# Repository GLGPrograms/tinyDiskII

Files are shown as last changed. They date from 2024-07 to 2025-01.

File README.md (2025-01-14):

# tinyDiskII

Homemade floppy disk emulator for Apple II series computers

> :warning: **Work in progress**: read carefully the README before trying to reproduce this project!

tinyDiskII

tinyDiskII is able to simulate an [Apple Disk II](https://it.wikipedia.org/wiki/Disk_II) both in reading and writing.
Disk images are stored into a FAT16 formatted SD Card.
Each disk image must be a DOS 3.3 floppy image, saved as .NIC.
A cross platform .NIC <-> .DSK conversion tool will be available soon on this repository.
Floppy formatting is currently not supported, but it is currently under developement.

## BOM

| Reference(s) | Description | Notes |
| :--- | :---: | :---: |
| C1, C2, C3, C4, C5, C6, C8, C9, C10, C11, C12 | 0805 100n Capacitor | |
| D1, D2 | 0805 Red LED | |
| J1 | 2x3 male jumper | ICSP connector |
| J2 | SMD SD Card slot | |
| J3 | THT USB B Mini connector  |  Mount for USB debug |
| J4 | 2x10 male connector | DiskII connector |
| R5, R6 | 330 | |
| R2, R3, R4, R7, R8, R9, R10, R11, R12, R15 | 10k | |
| R13, R14 | 0 | Replaced with a bridge |
| SW1 | RotaryEncoder with switch | |
| U2 | SN74LVC244 | 5V tolerant buffer |
| U3 | CH340C |  Mount for USB debug |
| U4 | ATxmega16A4U-A | MCU |
| U5 | 74AHCT125 | Level shifter |
| U7 | 0.96" OLED I2C | 7-pin model |
| U10 | AP1117-33 |  3v3 linear regulator  |

### Do Not Place, reserved for future implementations

| Reference(s) | Feature |
| :--- | :---: |
| U1 | Flash/EEPROM interface |
| C12 | " |
| R1 | " |
| C13, C14 | USB ESD |
| R13, R14 | " |
| D3, D4 | " |
| C7 | USB self reset |
| J5 |  Debugging connector |

## Schematics and PCB

> :warning: Schematics and PCB layout can be found in `/schematics` folder. Please note that I had physically implemented only rev1.0, which requires some hardware patches. The issues were fixed in rev1.1, but I never put it into production. Build it at your own risk.

## Firmware

Firmware source code is in `/firmware` folder.
Code can be compiled on a linux/wsl machine through `make` command.
Make sure you have `make` and `avr-gcc` toolchanin installed.
Output binary will be generated as `/firmware/output/tinyDiskII.hex`.

In `/firmware/tests` there are some unit tests that can run on host system.
They can be compiled and executed with:

```bash
cd firmware/tests
cmake -B build .
cd build
cmake --build .
./tinyDiskII-tests
```

### Command line linterface

The serial interface is mainly used for application logging.
If no OLED display is detected, the serial interface is enabled for receiving commands.
If the OLED is connected, the command interpreter is disabled to avoid conflicts.

The following table resumes the available commands.

| Command | Arguments  | Description |
| :--- | :--- | :--- |
| `INIT`  | none | Initialize the SD Card (1) |
| `CWD` | `dirname`  | Change woring directory to `dirname` |
| `UP` | none | Change working director to the parent directory |
| `LST` | none | List files and directory in the current working directory |
| `SET` | `filename` | Select `filename`, in current working directory, as currently inserted disk (2) |
| `REM` | none | Remove currently inserted disk |
| `FAT` | `upto` | Prints FAT entries of selected file up to index `upto` (debug) |
| `INFO`  | `t` `s` | Prints .NIC file informations about sector `s` in track `t` (debug) |

1. If OLED is not connected, the SD Card must be manually initialized.
2. At startup, no disk is inserted.

## Changelog

* rev1.0: first version
* rev1.1: fixes the issues present in rev1.0:

  * LV_DISK_READ connected to U4 pin 21;
  * SD_WP connected to U4 pin 22;
  * SD_DETECT connected to U4 pin 23;
  * Added 10K pull-up resistor to DISK_WRITE_EN;
  * Pin 4 and 16 of U3 are shorted together.

## Contributors and references

* The whole projects borns as a custom implementation of Koichi Nishida's SdiskII [[1]](https://tulip-house.ddo.jp/digital/SDISK2/english.html) [[2]](https://github.com/suaide/SDisk2), which I used as a starting point for firmware developement.
* Jörg Hagedorn made a replica of the tinyDiskII hardware rev1.1 and he found a bug in the SD sector's addressing, now fixed.
* Kamen Angelov made a replica of the tinyDiskII hardware rev1.1, he found a bug with SDHC card and he sent some fix proposal.

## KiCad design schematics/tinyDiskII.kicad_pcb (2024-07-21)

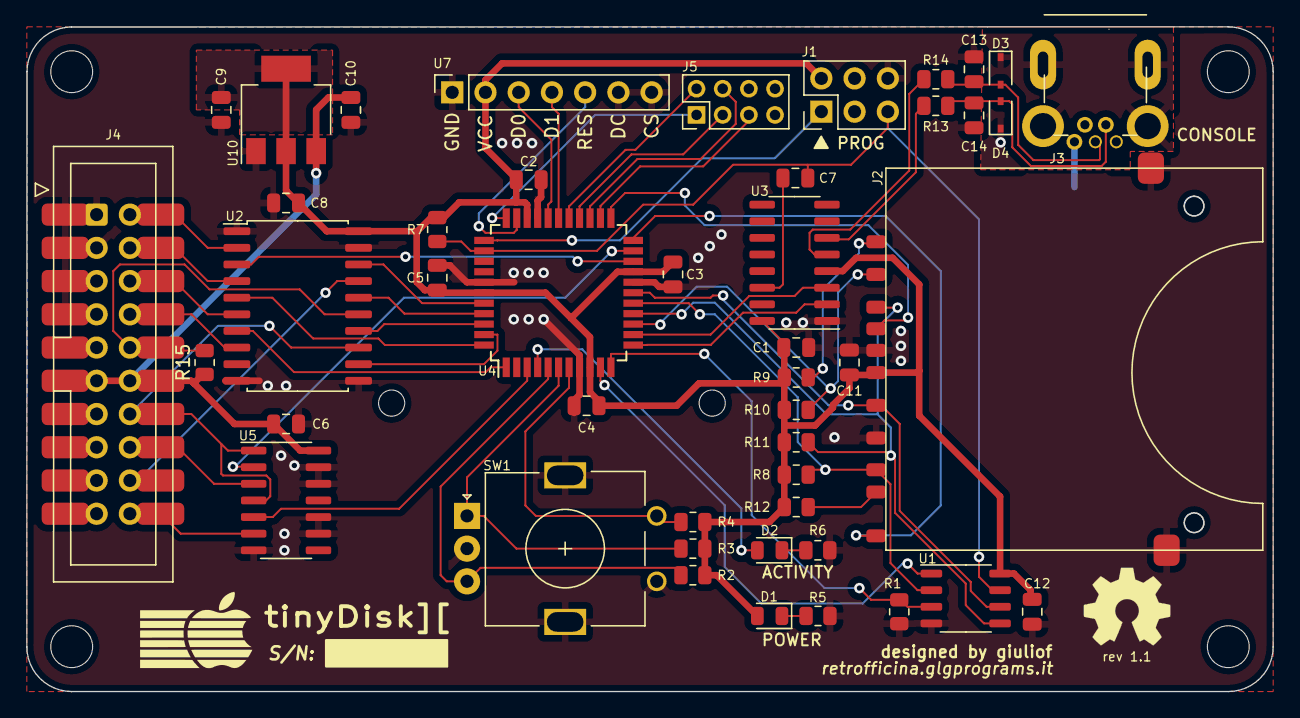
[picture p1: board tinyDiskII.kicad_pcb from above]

Board: 2 copper layers, 95.3 x 50.8 mm, 52 parts (0 on the bottom side), 55 nets.

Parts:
C1, C3, C4, C5, C6, C8, C9, C10, C11, C12: 100n; C_0805_2012Metric
C7, C13, C14: C; C_0805_2012Metric
C?: 100n; C_0805_2012Metric
D1, D2: LED; LED_0805_2012Metric
D3, D4: -; D_SOD-323
H1, H2, H3, H4: MountingHole; MountingHole_3.2mm_M3
J2: SD_Card; SDCard
J3: USB_B_Mini; USB_Mini-B_THT_generic
J4: APPLEII_DISK_CONNECTOR; IDC-Header_2x10_P2.54mm
J5: Ext; PinHeader_2x04_P2.00mm_Vertical
J?: AVR-PDI-6; PinHeader_2x03_P2.54mm_Vertical
R1: R; R_0805_2012Metric
R2, R3, R4, R7, R8, R9, R10, R11, R12, R15: 10k; R_0805_2012Metric
R5, R6: 330; R_0805_2012Metric
R13, R14: 10; R_0805_2012Metric
SW1: RotaryEncoder_Switch
SYM1: GraphicSymbol; Apple_Logo
SYM2: Logo_Open_Hardware_Small; OSHW-Symbol_6.7x6mm_SilkScreen
U1: MX25R3235FM1xx0; SOP-8_3.9x4.9mm_P1.27mm
U2: SN74LVC244; SOIC-20W_7.5x12.8mm_P1.27mm
U3: CH340C; SOIC-16_3.9x9.9mm_P1.27mm
U5: 74AHCT125; SOIC-14_3.9x8.7mm_P1.27mm
U7: OLED_MULTI
U10: AP1117-33; SOT-223-3_TabPin2
U?: ATxmega16A4U-A; TQFP-44_10x10mm_P0.8mm

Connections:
+3V3: C1.1, C3.1, C4.1, C5.1, C8.1, C9.1, C11.1, C12.1, C?.1, D1.2 (A), J2.4 (VDD), J?.2 (VCC), R2.2, R3.2, R4.2, R7.2, R8.1, R9.1, R10.1, R11.1, R12.1, U1.8 (VCC), U2.20 (VCC), U3.4 (V3), U3.16 (VCC), U7.2 (VCC), U10.2 (VO), U?.9 (VCC), U?.19 (VCC), U?.31 (VCC), U?.39 (AVCC)
+5V: C6.1, C10.1, J4.11 (+5V), J4.12 (+5V), R15.1, U5.14 (VCC), U10.3 (VI)
/ACT_LED: D2.2 (A), U?.4 (AREFB/PB0)
/D'N: R14.1, U3.6 (UD-)
/D'P: R13.1, U3.5 (UD+)
/DAT1: J2.8 (DAT1), R12.2
/DAT2: J2.9 (DAT2), R9.2
/DISK_EN: J4.14 (EN), U2.13 (2A2), U5.1, U5.4
/DISK_READ: J4.16 (READ), U5.3
/DISK_WRITE: J4.18 (WRITE), U2.17 (2A0)
/DISK_WRITE_EN: J4.10 (WR_EN), R15.2, U2.15 (2A1)
/DN: C14.1, D4.2 (A2), J3.2 (D-), R14.2
/DP: C13.1, D3.2 (A2), J3.3 (D+), R13.2
/ENC_A: R3.1, SW1.A, U?.6 (PB2)
/ENC_B: R2.1, SW1.B, U?.5 (PB1)
/ENC_BTN: R4.1, SW1.S1, U?.7 (PB3)
/FLASH_CS: U1.1 (~CS), U?.10 (PC0)
/FLASH_WP: R1.2, U1.3 (~WP/SIO2), U?.11 (PC1)
/LV_DISK_EN: U2.7 (2Y2), U?.1 (PA5)
/LV_DISK_READ: U5.2, U?.21 (PD1)
/LV_DISK_WRITE: U2.3 (2Y0), U?.20 (PD0)
/LV_DISK_WRITE_EN: U2.5 (2Y1), U?.44 (PA4)
/LV_PHI0: U2.18 (1Y0), U?.40 (AREFA/PA0)
/LV_PHI1: U2.16 (1Y1), U?.41 (PA1)
/LV_PHI2: U2.14 (1Y2), U?.42 (PA2)
/LV_PHI3: U2.12 (1Y3), U?.43 (PA3)
/LV_WRITE_PROTECT: U5.5, U?.3 (PA7)
/OLED_RES: U7.5 (RES), U?.32 (PE2)
/OLED_SCL: U7.3 (D0), U?.29 (PE1)
/OLED_SDA: U7.4 (D1), U?.28 (PE0)
/PD4: J5.5, U?.24 (PD4)
/PD5: J5.4, U?.25 (PD5)
/PD6: J5.3, U?.26 (PD6)
/PD7: J5.2, U?.27 (PD7)
/PDI_CLK: C7.1, J?.5 (CLOCK), R7.1, U1.7 (~RESET/SIO3), U?.35 (~RESET/PDI_CLK)
/PDI_DATA: J?.1 (DATA), U?.34 (PDI_DATA)
/PE3: J5.1, U?.33 (PE3)
/PH0: J4.2 (PH0), U2.2 (1A0)
/PH1: J4.4 (PH1), U2.4 (1A1)
/PH2: J4.6 (PH2), U2.6 (1A2)
/PH3: J4.8 (PH3), U2.8 (1A3)
/SD_CS: J2.1 (CD/DAT3), R10.2, U?.14 (PC4)
/SD_DETECT: J2.10 (CARD_DETECT), U?.23 (PD3)
/SD_WP: J2.11 (WRITE_PROTECT), U?.22 (PD2)
/SPI_MISO: J2.7 (DAT0), R8.2, U1.2 (SO/SIO1), U?.16 (PC6)
/SPI_MOSI: J2.2 (CMD), R11.2, U1.5 (SI/SIO0), U?.15 (PC5)
/SPI_SCK: J2.5 (CLK), U1.6 (SCLK), U?.17 (PC7)
/UART_RXD: U3.2 (TXD), U?.12 (PC2)
/UART_TXD: U3.3 (RXD), U?.13 (PC3)
/USB_SHIELD: D3.1 (A1), D4.1 (A1), J3.6 (Shield)
/WRITE_PROTECT: J4.20 (PROTECT), U5.6
GND: C1.2, C3.2, C4.2, C5.2, C6.2, C8.2, C9.2, C10.2, C11.2, C12.2, C13.2, C14.2, C?.2, J2.3 (VSS), J2.6 (VSS), J2.12 (SHELL1), J2.13 (SHELL2), J3.5 (GND), J4.1 (GND), J4.3 (GND), J4.5 (GND), J4.7 (GND), J?.6 (GND), R1.1, R5.2, R6.2, SW1.C, SW1.MP (SHIELD), SW1.S2, U1.4 (GND), U2.1 (1OE), U2.10 (GND), U2.11 (2A3), U2.19 (2OE), U3.1 (GND), U5.7 (GND), U5.9, U5.10, U5.12, U5.13, U7.1 (GND), U7.6 (DC), U7.7 (CS), U10.1 (GND), U?.8 (GND), U?.18 (GND), U?.30 (GND), U?.38 (GND)
unnamed: C7.2, U3.14 (~RTS)
unnamed: D1.1 (K), R5.1
unnamed: D2.1 (K), R6.1

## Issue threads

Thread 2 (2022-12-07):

SD Card initialization fails after power up

giuliof, 2022-12-07:
Initialization completes correctly if a reset is issued.
Maybe an incorrect power up sequence?

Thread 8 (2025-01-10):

Addressing error with SDHC cards

giuliof, 2025-01-10:
Kamen Angelov made a replica of the project and found a bug when using SDHC  cards.
It that case command 17 (`SD_CMD_READ_SINGLE_BLOCK`) needs block unit address (512 bytes unit) instead of byte size unit.

This may be solved introducing the following patch code when giving the address to the `SD_CMD_READ_SINGLE_BLOCK` command.

```c
uint32_t addressToBlock(uint32_t address) {
    if (type == SD_SDHC) {
        return address / SDCARD_BLOCK_SIZE;
    }

    return address;
}
```

Further tests needed.

Closed 2025-01-14.

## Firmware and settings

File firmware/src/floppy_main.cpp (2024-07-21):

/* * * * * * * * * * * * * * * * *  INCLUDES  * * * * * * * * * * * * * * * * */

#include "floppy_main.h"

#include <avr/interrupt.h>
#include <avr/io.h>

#include <util/delay.h>

#include "sdcard.h"
#include "sdcard_nic.h"
#include "util/macro.h"
#include "util/port.h"

#include "debug.h"

/* * * * * * * * * * * * * PRIVATE MACROS AND DEFINES * * * * * * * * * * * * */

// Writing buffer size
#define WRITING_BUFFER_SIZE (350)
// Volume number is always the same
#define volume (0xFE)

// IO defines
#define FLOPPY_DISK_WRITE      D, 0
#define FLOPPY_PH              A, 0
#define FLOPPY_PH_MASK         0xF
#define FLOPPY_DISK_WRITE_EN   A, 4
#define FLOPPY_DISK_EN         A, 5
#define FLOPPY_DISK_READ_EX    A, 6
#define FLOPPY_DISK_READ       D, 1
#define FLOPPY_DISK_WRITE_PROT A, 7

#define WRITE_CAPABLE (true)

/* * * * * * * * * * * * * STATIC FUNCTION PROTOTYPES * * * * * * * * * * * * */

// Reading routines
static void abort_reading();
static void irq_reading();

// Writing routines
static uint8_t floppy_read_data();
static void init_writing();
static void end_writing();
static void check_data();
static void write_pinchange();
static void write_idle();
static void write_back(void);

/* * * * * * * * * * * * * * *  STATIC VARIABLES  * * * * * * * * * * * * * * */

// DISK II status
// Formatting operation has been detected
static bool formatting = false;
// Physical track
static uint8_t ph_track; // 0 - 69
// Disk sector
static uint8_t sector; // 0 - 15
// Number of read bits from NIC file sector (maximum of 512 bytes)
static uint16_t bitbyte; // 0 - (8*512-1)
static uint8_t write_buffer[WRITING_BUFFER_SIZE];
static uint8_t write_data = 0x00;
static uint8_t write_bitcount = 0;
static bool synced = false;
// Update sector request
static volatile bool prepare = true;

/* * * * * * * * * * * * * * *  STATIC FUNCTIONS  * * * * * * * * * * * * * * */

/* - - - - - - - - - - - - - - Low-level methods  - - - - - - - - - - - - - - */

static uint8_t floppy_write_in()
{
  return (Port(FLOPPY_DISK_WRITE).IN & PinMsk(FLOPPY_DISK_WRITE)) ? 1 : 0;
}

static uint8_t floppy_write_enable()
{
  return (Port(FLOPPY_DISK_WRITE_EN).IN & PinMsk(FLOPPY_DISK_WRITE_EN)) ? 0 : 1;
}

/* - - - - - - - - - - - - - floppy reading methods - - - - - - - - - - - - - */

static void abort_reading()
{
  if (bitbyte < (402 * 8))
  {
    nic_abort_read(bitbyte);
    bitbyte = 402 * 8;
  }
}

static void irq_reading()
{
  uint8_t readpulse;

  // disable match
  TCD0.CCB = 0xFFFF;

  // Still fetching data
  if (prepare)
    return;

  if (bitbyte < (402 * 8))
  {
    // Fetch bit from sdcard
    readpulse = nic_get_bit();

    // 3us low, then 1us high pulse
    if (readpulse)
      TCD0.CCB = 3e-6 * (F_CPU);

    bitbyte++;

    return;
  }

  prepare = true;
}

/* - - - - - - - - - - - - - floppy writing methods - - - - - - - - - - - - - */

static uint8_t floppy_read_data()
{
  static uint8_t magstate = 0;
  uint8_t old_magstate = magstate;
  magstate = floppy_write_in();
  return magstate ^ old_magstate;
}

// this function should be called when a write request is asserted
static void init_writing()
{
  cli();
  // Disable match
  TCD0.CCB = 0xFFFF;
  synced = false;
  write_bitcount = 0;
  floppy_read_data();
  TCD0.CNT = 0x0000;
  TCD0.INTFLAGS = TC0_OVFIF_bm;
}

// this function should be called when write request is de-asserted
static void end_writing()
{
  write_back();
  TCD0.CNT = 0x0000;
  TCD0.INTFLAGS = TC0_OVFIF_bm;
  sei();
}

static void check_data()
{
  static uint16_t bufsize;
  if (!synced && write_data == 0xD5)
  {
    synced = true;
    bufsize = 0;
    goto push;
  }

  if (synced && bufsize < WRITING_BUFFER_SIZE)
  {
    write_bitcount++;
    if (write_bitcount == 8)
    {
    push:
      write_bitcount = 0;
      write_buffer[bufsize++] = write_data;
    }
  }
}

static void write_pinchange()
{
  // disable match
  // TCD0.CCB = 0xFFFF;
  write_data <<= 1;
  write_data |= 1;
  TCD0.CNT = 0x0000;
  TCD0.INTFLAGS = TC0_OVFIF_bm;
  check_data();
}

static void write_idle()
{
  // disable match
  // TCD0.CCB = 0xFFFF;
  write_data <<= 1;
  TCD0.INTFLAGS = TC0_OVFIF_bm;
  check_data();
}

// write back writeData into the SD card
static void write_back(void)
{
  static unsigned char sec;

  // if (bit_is_set(PIND,3)) return;
  if (write_buffer[2] == 0xAD)
  {
    if (!formatting)
    {
      abort_reading();
      nic_write_sector(write_buffer, volume, ph_track >> 1, sector);
      write_buffer[2] = 0;
      prepare = true;
    }
    else
    {
      sector = sec;
      formatting = false;
      if (sec == 0xf)
      {
        // cancel reading
        abort_reading();
        prepare = true;
      }
    }
  }
  if (write_buffer[2] == 0x96)
  {
    sec = (((write_buffer[7] & 0x55) << 1) | (write_buffer[8] & 0x55));
    formatting = true;
  }
}

/* * * * * * * * * * * * * * *  GLOBAL FUNCTIONS  * * * * * * * * * * * * * * */

void floppy_init()
{
  // Input stepper
  Port(FLOPPY_PH).DIRCLR = FLOPPY_PH_MASK;

  bitbyte = 0;

  /*
   *
   *      /|     /|     /|     /|
   *     / |    / |    / |    / |
   *    /  |   /  |   /  |   /  |
   *   /   |  /   |  /   |  /   |
   *  /    | /    | /    | /    |
   * /     |/     |/     |/     |
   *      _      _             _
   * ____| |____| |___________| |
   *      1      1      0      1
   */

  // Timer. Set period to 4us,
  TCD0.PER = 4e-6 * (F_CPU);
  // PWM mode, output compare enabled on CCB
  TCD0.CTRLB = (TC_WGMODE_SINGLESLOPE_gc << TC0_WGMODE0_bp) | TC0_CCBEN_bm;
  // interrupt on overflow,
  TCD0.INTCTRLA = (TC_OVFINTLVL_HI_gc) << TC0_OVFIF_bp;

  // Inputs
  Port(FLOPPY_DISK_WRITE).DIRCLR = PinMsk(FLOPPY_DISK_WRITE);
  Port(FLOPPY_DISK_WRITE_EN).DIRCLR = PinMsk(FLOPPY_DISK_WRITE_EN);
  Port(FLOPPY_DISK_EN).DIRCLR = PinMsk(FLOPPY_DISK_EN);
  Port(FLOPPY_DISK_READ_EX).DIRCLR = PinMsk(FLOPPY_DISK_READ_EX);
  // Outputs
  Port(FLOPPY_DISK_READ).DIRSET = PinMsk(FLOPPY_DISK_READ);
  Port(FLOPPY_DISK_WRITE_PROT).DIRSET = PinMsk(FLOPPY_DISK_WRITE_PROT);

  // output compare enabled (inverted)
  Port(FLOPPY_DISK_READ).PIN1CTRL = PORT_INVEN_bm;
  // output compare register to MAX?
  TCD0.CCB = 0xFFFF;

  // Enable clock to the TCD0
  TCD0.CTRLA = TC_CLKSEL_DIV1_gc;
}

/* - - - - - - - - - - - - - - Low-level methods  - - - - - - - - - - - - - - */

void floppy_write_protect(bool protect)
{
  if (protect)
    Port(FLOPPY_DISK_WRITE_PROT).OUTSET = PinMsk(FLOPPY_DISK_WRITE_PROT);
  else
    Port(FLOPPY_DISK_WRITE_PROT).OUTCLR = PinMsk(FLOPPY_DISK_WRITE_PROT);
}

bool floppy_drive_enabled()
{
  if (Port(FLOPPY_DISK_EN).IN & PinMsk(FLOPPY_DISK_EN))
    return false;
  return true;
}

// Timer IRQ: called every 4us to output data signal (see comment in floppy_init)
ISR(TCD0_OVF_vect)
{
  irq_reading();
}

/* - - - - - - - - - - - - - - High-level methods - - - - - - - - - - - - - - */

void floppy_main()
{
  // Current stepper offset (0 to 3)
  static uint8_t ofs = 0;
  // Latest stepper offset
  static uint8_t old_ofs = 0;

  // Prepare variables
  cli();
  bitbyte = 0;
  prepare = true;
  // Leave track at last position...
  // ph_track = 0;
  sector = 0;
  sei();

  while (floppy_drive_enabled())
  {
    // Prepare for writing?
    if (WRITE_CAPABLE && floppy_write_enable())
    {
      init_writing();

      uint8_t magstate = floppy_write_in();

      do
      {
        uint8_t new_magstate = floppy_write_in();
        if (magstate != new_magstate)
        {
          write_pinchange();
          magstate = new_magstate;
        }
        if (TCD0.INTFLAGS & TC0_OVFIF_bm)
        {
          write_idle();
        }
      } while (floppy_write_enable());

      end_writing();
    }


    /* * * Update physical track position * * */
    uint8_t stp_pos = (Port(FLOPPY_PH).IN & FLOPPY_PH_MASK);

    ofs = ((stp_pos == 0b00001000)
               ? 3
               : ((stp_pos == 0b00000100)
                      ? 2
                      : ((stp_pos == 0b00000010) ? 1
                                                 : ((stp_pos == 0b00000001) ? 0 : ofs))));
    if (ofs != old_ofs)
    {
      if (ofs == ((old_ofs + 1) & 0x3))
        ph_track++;
      else if (ofs == ((old_ofs - 1) & 0x3))
        ph_track--;

      old_ofs = ofs;

      // < 0
      if (ph_track > 70)
        ph_track = 0;
      // > fine tracce
      else if (ph_track > 69)
        ph_track = 69;

      // DEBUG good old printf debug
      // debug_printP(PSTR("%x\n\r"), ph_track);
      // ... do not interrupt a sector reading when changing track
    }

    if (prepare)
    {
      // mute interrupts during update. 0 will be sent
      cli();

      if (bitbyte == (402 * 8))
      {
        // Sector is ended,
        // discard 112 byte (including CRC 2 byte)
        nic_abort_read(bitbyte);
      }

      sdcard_set_mode(SPI, 1);

      // Move to the next sector circularly
      // Sectors does not have a particular alignemnt between track and track.
      // Then, sector is always incremented
      sector = ((sector + 1) & 0xf);
      nic_update_sector(ph_track >> 1, sector);
      bitbyte = 0;
      prepare = false;

      sdcard_set_mode(BITBANG_FAST, 0);

      sei();
    }
  }

  debug_printP(PSTR("Reading done\n\r"));

  // wait till last irq
  while (!prepare)
    ;
  if (bitbyte == (402 * 8))
  {
    // Sector is ended,
    // discard 112 byte (including CRC 2 byte)
    nic_abort_read(bitbyte);
  }

  sdcard_set_mode(SPI, 1);

  bitbyte = 0;
  ph_track = 0;
  ofs = 0;
  old_ofs = 0;
}

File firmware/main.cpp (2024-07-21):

/**
 * @file main.c
 * @author Giulio (giulio@glgprograms.it)
 * @brief Kickstart and setup code
 * @version 0.1
 * @date 2022-03-03
 *
 * @copyright Copyright (c) 2022
 *
 */

#include <avr/interrupt.h>
#include <avr/io.h>
#include <util/delay.h>

#include "src/clock.h"
#include "src/floppy_main.h"
#include "src/prompt.h"
#include "util/port.h"

#include "src/sdcard.h"
#include "src/sdcard_gpio.h"
#include "src/sdcard_nic.h"
#include "src/sdcard_fat.h"

#include "src/oled_gui.h"
#include "src/oled_lcd.h"
#include "src/encoder.h"

#include "debug.h"

// Enable GUI
#define DISPLAY_ENABLED (true)

static void cli_mainloop() __attribute__((noreturn));
static void gui_mainloop() __attribute__((noreturn));
static void display_update_file_list(uint16_t fat_idx);

int main()
{
  // If display is not connected or disabled, use CLI
  bool cli_mode = true;

  // Set up PLL to reach desired clock speed
  clk_init();

  // Configure SDcard I/O
  sdcard_init();

  // Configure prompt uart
  prompt_init();

  // Configure floppy
  floppy_init();

  // Initialize OLED display
  if (DISPLAY_ENABLED)
    cli_mode = !oled_init();

  PMIC.CTRL |= PMIC_HILVLEN_bm | PMIC_MEDLVLEN_bm | PMIC_LOLVLEN_bm;
  sei();

  if (cli_mode)
    cli_mainloop();
  else
    gui_mainloop();
}

static void cli_mainloop()
{
  while (1)
  {
    prompt_main();

    // Do nothing if drive is disabled
    if (floppy_drive_enabled() && nic_file_selected())
    {
      debug_printP(PSTR("Reading enabled\n\r"));
      floppy_main();
    }
  }
}

static void gui_mainloop()
{
  encoder_init();

  // Currently "hovered" fat entry
  uint16_t fat_entry;
  // Currently selected folder and file names
  char file_name[FAT_FILENAME_STRLEN] = "";
  char cwd_name[FAT_FILENAME_STRLEN] = "";

  oled_gui_volume_name(NULL, false);

  while (1)
  {
    if (!sdcard_present())
    {
      oled_gui_error("Please insert an SD card");

      while (!sdcard_present())
        ;
      // "Debouncing", assure that card is correctly inserted
      _delay_ms(500);
    }

    oled_gui_error("Initializing SD card, please wait");

    // Initialize SD card
    if (!sdcard_card_init() || !sdcard_fat_init())
    {
      oled_gui_error("Error: SDcard failed in initialization");
      // Must remove SDcard to proceed
      while (sdcard_present())
        ;

      continue;
    }

    oled_gui_volume_name(NULL, sdcard_locked());
    oled_gui_cwd_currentfile(NULL, NULL);

    // Populate file list on home screen
    fat_entry = 0xFFFF;
    // TODO if fail, error: no file in this SDCARD
    fat_next(&fat_entry);
    display_update_file_list(fat_entry);

    while (sdcard_present())
    {
      int8_t delta = encoder_update();
      // Update file pointer and eventually update file list
      if (delta != 0)
      {
        if (delta > 0) fat_prev(&fat_entry);
        if (delta < 0) fat_next(&fat_entry);
        display_update_file_list(fat_entry);
      }

      if (encoder_clicked())
      {
        if (fat_is_directory(fat_entry))
        {
          // Get directory name
          fat_get_entry_name(cwd_name, fat_entry);
          // Enter in directory
          fat_cwd(fat_entry);
          // Reset pointer in directory entry table, then validate for first file
          fat_entry = 0xFFFF;
          fat_next(&fat_entry);
          // Update display with folder content
          display_update_file_list(fat_entry);
        }
        else
        {
          bool ro = sdcard_locked() || fat_is_ro(fat_entry);
          nic_build_fat(fat_entry);
          floppy_write_protect(ro);
          fat_get_entry_name(file_name, fat_entry);
          // FIXME strip extension
          for(uint8_t i = 0; i <= 8; i++)
            if (file_name[i] == '.')
            {
              file_name[i] = '\0';
              break;
            }
        }
        oled_gui_cwd_currentfile(cwd_name, file_name);
      }

      // Do nothing if drive is disabled
      if (floppy_drive_enabled() && nic_file_selected())
      {
        debug_printP(PSTR("Reading enabled\n\r"));

        oled_gui_set_busyflag(true);

        // While floppy is selected, floppy_main will never return
        floppy_main();

        oled_gui_set_busyflag(false);
      }
    }
  }
}

static void display_update_file_list(uint16_t fat_idx)
{
  // Invert for first file (hovered)
  oled_invert(true);

  int i;

  for (i = 0; i < 6; i++)
  {
    char filename[FAT_FILENAME_STRLEN];

    fat_get_entry_name(filename, fat_idx);

    oled_gui_fileline(filename, fat_is_directory(fat_idx), fat_is_ro(fat_idx), i);

    oled_invert(false);

    // If no more files, clean lines then stop
    if (!fat_next(&fat_idx)) break;
  }

  for (i++; i < 6; i++)
    oled_gui_fileline(NULL, false, false, i);
}

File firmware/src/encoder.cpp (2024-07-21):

/* * * * * * * * * * * * * * * * *  INCLUDES  * * * * * * * * * * * * * * * * */

#include "encoder.h"

#include <avr/io.h>

#include "util/port.h"
#include "debug.h"

/* * * * * * * * * * * * * PRIVATE MACROS AND DEFINES * * * * * * * * * * * * */

#define ENC_A B, 1
#define ENC_B B, 2
#define BTN_PIN B, 3

/* * * * * * * * * * * * * * *  STATIC VARIABLES  * * * * * * * * * * * * * * */

static uint8_t old_encoder_pos = 0;
static bool old_btn_status;

/* * * * * * * * * * * * * * *  GLOBAL FUNCTIONS  * * * * * * * * * * * * * * */

void encoder_init()
{
  // Configure encoder pushbutton as input with pull-up
  Port(BTN_PIN).DIRCLR |= PinMsk(BTN_PIN);
  PinCtrl(BTN_PIN) = PORT_OPC_PULLUP_gc;
  old_btn_status = Port(BTN_PIN).IN & PinMsk(BTN_PIN);

  // Configure encoder phases pin
  Port(ENC_A).DIRCLR |= (PinMsk(ENC_A) | PinMsk(ENC_B));
  // Set ENC_A and ENC_B as low level sense
  PinCtrl(ENC_A) = PORT_ISC_LEVEL_gc | PORT_OPC_PULLUP_gc;
  PinCtrl(ENC_B) = PORT_ISC_LEVEL_gc | PORT_OPC_PULLUP_gc;
  // Set ENC_A as mux input for event channel 0
  // TODO pin port and number is hardcoded
  EVSYS.CH0MUX = EVSYS_CHMUX_PORTB_PIN1_gc;
  // Enable quadrature decoding and digital filter
  EVSYS.CH0CTRL = EVSYS_QDEN_bm | EVSYS_DIGFILT_8SAMPLES_gc;
  // Set quadrature decoder as action for TCC (timer/counter C), source from Event ch0
  TCC0.CTRLD = TC_EVACT_QDEC_gc | TC_EVSEL_CH0_gc;
  // Set period and counter register (use counter as 8 bit)
  TCC0.PER = 0xFF;
  TCC0.CNT = 0x00;
  // Enable TCC without prescaling
  TCC0.CTRLA = TC_CLKSEL_DIV1_gc;
}

bool encoder_clicked()
{
  bool btn_status;
  bool ret;

  btn_status = Port(BTN_PIN).IN & PinMsk(BTN_PIN);

  ret = btn_status && !old_btn_status;

  old_btn_status = btn_status;

  return ret;
}

int8_t encoder_update()
{
  uint8_t pos = TCC0.CNT;

  // One encoder tick adds 2 counter steps
  int8_t delta = (pos - old_encoder_pos) >> 1;

  // Update last position only if a tick is detected
  if (delta != 0)
    old_encoder_pos = pos;

  return delta;
}

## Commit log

2022-10-01 [schematics] added Kicad project for hw rev 1.0
    [tinyDiskII.kicad_pcb, tinyDiskII.kicad_sch]
2022-10-01 [schematics] Removed some notes from schematic
    [tinyDiskII.kicad_sch]
2022-10-01 [schematics] Updated missing values
    [tinyDiskII.kicad_sch]
2024-07-21 [schematics] integrated changes for rev2, removed some ERC warnings
    [tinyDiskII.kicad_sch]
2024-07-21 [schematics] Updated power symbols
    [tinyDiskII.kicad_sch]
2024-07-21 [schematics] Updated power symbols, part 2
    [tinyDiskII.kicad_sch]
2024-07-21 [schematics] Removed old tracks, rewire in progress
    [tinyDiskII.kicad_pcb]
2024-07-21 [schematics] updated routing fixing errata of rev1.0
    [tinyDiskII.kicad_pcb, tinyDiskII.kicad_sch]
2024-07-21 [sdcard] faster SPI
    /4 prescaler instead of /64
2024-07-21 [schematics] rev1.1 label
    [tinyDiskII.kicad_pcb, tinyDiskII.kicad_sch]
2024-07-21 [encoder] use in-hardware quadrature encoder system instead of software
2024-07-21 [repo] Updated readme with changes in schematics (rev1.1)
2024-07-21 [sdcard] Fixed typo in initialization procedure
    After acmd 41, must wait for empty R1 (0x00), not IDLE (0x01).
    [sdcard.cpp]
2024-07-21 [schematics] Missing track, fixed
    [tinyDiskII.kicad_pcb]
2025-01-14 docs: added explanation of the new debug commands, cited Jörg for his contribution in this fix
    [prompt.cpp]
2025-01-14 [sdcard] fix bad addressing for SDHC cards
    [sdcard.cpp]
2026-05-04 [encoder] fixed wrong encoder steps
    - Counter register is on 16bit;
    - Each encoder turn is 4 steps;
    - Delta is signed, should use signed division instead of raw shift.
2026-05-06 [gpio] added activity led
2026-05-06 [sdcard] first steps toward rev 2.0
    - swapped SDCARD_CLK and SDCARD_DO pins to make use of syncronous UART
    (MSPI mode).
    - Switched from SPI to UART, MSPI mode.
2026-05-06 [dma] first working code with DMA, only read is implemented
    ALERT: AN HARDWARE CHANGE IS NEEDED, THIS CODE IS COMPATIBLE ONLY WITH
    HARDWARE REV2.0.
    - disabled writing, since is currently not implemented through DMA;
    - removed bitbanging, no more needed;
    - sdcard SPI is handled with USART in MSPI mode, this need pin swap
    between MOSI and SCK;
    - spi speed is incremented to 16MHz. Initialization speed is fixed to
    50kHz;
    - added DMA for floppy sector reading.
2026-05-06 [dma] read/write code with DMA implemented, now with formatting support
    Tested with AppleDOS INITIALIZE command and CopyII+ V5.
    - Writing buffer size increased to keep whole SD Card sector, plus CRC
    and "end of data token". Buffer is mostly initialized at startup, only
    address and data fields are changed at runtime.
    - New writing state machine, which detects the currently writing field
    and updates the writing buffer accordingly.
    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
2026-05-06 [floppy] get current volume when changing sector's content
